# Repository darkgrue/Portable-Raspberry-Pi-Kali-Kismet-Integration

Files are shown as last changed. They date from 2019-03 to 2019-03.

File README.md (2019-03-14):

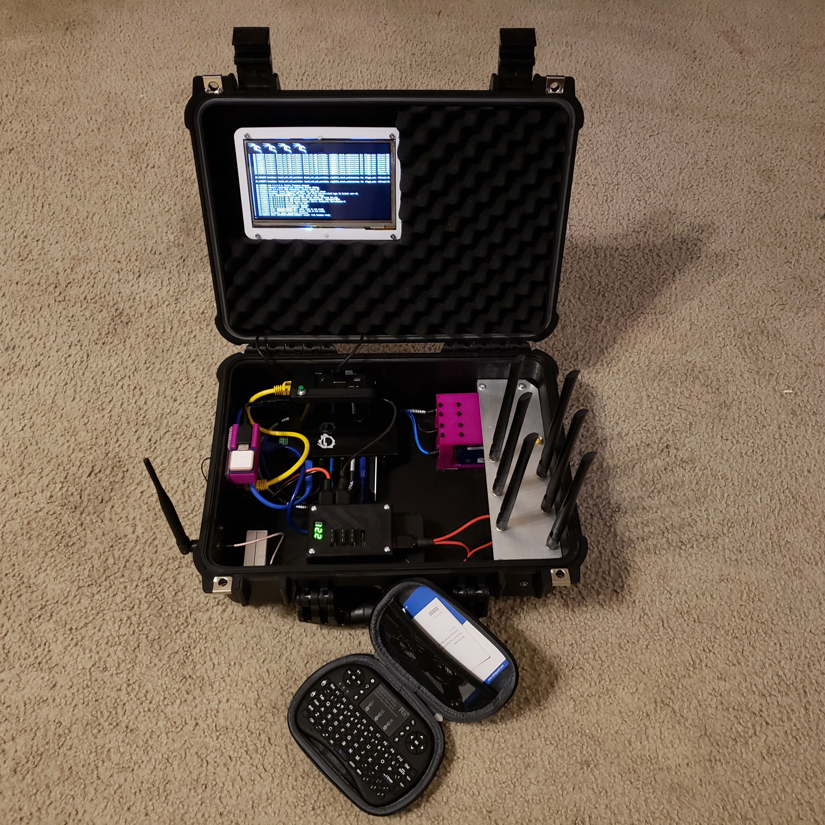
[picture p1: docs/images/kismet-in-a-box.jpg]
Kismet-in-A-Box


# Introduction

This is the basic documentation and model support files for a software and hardware integration project to build a transit-case-portable version of [Kismet](https://www.kismetwireless.net/) running on [Offsensive Security Kali Linux](https://www.offensive-security.com/kali-linux-arm-images/) (Kali Linux RaspberryPi 2 and 3) and a Raspberry Pi 3 Model B+.

The goal is to have a fully-functional Kismet platform that integrates all supported data sources in a completely portable form factor. In this case, the data sources being used are:
* Linux Wi-Fi (3x Alfa AWUS036ACH, RTL8812AU 802.11ac/a/b/g/n chipset)
* Linux Bluetooth (Cypress CYW43455 Bluetooth 4.2 chipset, onboard Raspberry Pi 3 Model B+)
* SDR RTL433 ([rtl_433](https://github.com/merbanan/rtl_433), 433.92 MHz generic data receiver)
* [Mousejack](https://github.com/BastilleResearch/mousejack) / nRF (Nordic Semiconductor nRF24LU1+ Logitech Unifying dongle, model C-U0007)
* GPS (u-blox 7, geolocation coordinates for devices)

There is room for expansion, and the as-built includes external connections for power, ethernet, and USB. A [DSTIKE Deauth Detector V2(Pre-flashed)](https://www.tindie.com/products/lspoplove/dstike-deauth-detector-v2pre-flashed/) has been included on the hub to independently monitor [deauthentication attacks](https://en.wikipedia.org/wiki/Wi-Fi_deauthentication_attack) on the 2.4GHz band.

# Bill of Materials
NOTE: Some items were bought in quantity (i.e. 3-pack, etc.) because of ease of procurement. In some cases there will be leftover/spare parts. Required quantities from packages are given for the as-built.

## Hardware
Qty. | Item | Approx. Price
------------ |------------ | -------------
1 |	[1/8" X 3" 6061 T6511 Aluminum extruded flat bar 12" long](https://www.ebay.com/itm/2-Pieces-1-8-X-3-ALUMINUM-6061-FLAT-BAR-12-long-T6511-New-Mill-Stock-125-x-3/350926360885) | $5.89
1 |	[Stanley National S838-946 2-1/2" Zinc Corner Brace- DPB113](https://www.amazon.com/dp/B00KQVM8E4) | $6.82
1 |	[Apache 3800 Weatherproof Protective Case - 16-5/16 In.](https://www.harborfreight.com/3800-weatherproof-protective-case-16-516-in-63927.html) | $39.99
as-needed | Misc screws, nuts and washers | varies
as-needed | 3M Dual Lock™ Reclosable Fastener SJ3560, Clear, 1 in | varies

## Computing Platform
Qty. | Item | Approx. Price
------------ |------------ | -------------
1 |	[CanaKit Raspberry Pi 3 B+ (B Plus) with 2.5A Power Supply (UL Listed)](https://www.amazon.com/dp/B07BC6WH7V) | $48.99
1 | [Samsung 128GB 100MB/s (U3) MicroSD EVO Select Memory Card with Adapter (MB-ME128GA/AM)](https://www.amazon.com/dp/B06XWZWYVP) | $28.99
1 |	[ModMyPi Modular (variable height) case for Raspberry Pi 2/3 - complete set with covers, spacers, screws & feet](https://www.amazon.com/dp/B01LYARY5D) | $19.95
1 | [SIIG 7-Port Industrial USB 3.0 Hub with 15KV ESD Protection](https://www.ebay.com/itm/SIIG-4-Port-and-7-Port-Industrial-USB-3-0-Hub-with-15KV-ESD-Protection/132678192728) | $34.99
1 | [Spell Foundry Sleepy Pi 2](https://spellfoundry.com/product/sleepy-pi-2/) | $56.33
1 |	[7inch HDMI 1024×600 Capacitive Touch Screen with Bicolor Case for Raspberry Pi](https://www.ebay.com/itm/7-HDMI-LCD-with-Case-800-480-Capacitive-Touch-Screen-for-Raspberry-Pi-BB-Black/262125842620) |  $67.15
1 | [Rii i8+ 2.4GHz Mini Wireless Keyboard with Touchpad Mouse,LED Backlit,Rechargable Li-ion Battery (Updated 2017,Backlit)](https://www.amazon.com/dp/B00WQG6A8C) | $21.95
1 | [Hard EVA Case for (Updated 2017,Backlit) Rii i8+ 2.4GHz Mini Wireless Keyboard by Hermitshell](https://www.amazon.com/dp/B01E8ILR60) | $9.99

## Power
Qty. | Item | Approx. Price
------------ |------------ | -------------
1 | [DC 12V 45A Anderson Powerpole Connector Power Distribution 1 input - 4 output](https://www.ebay.com/itm/DC-12V-45A-Anderson-Powerpole-Connector-Power-Distribution-1-input-4-output/183445188417) | $30.00
3 | 2A ATO blade fuse [2 required, 1 spare] | varies
1 | [TalentCell Rechargeable 72W 132WH 12V/11000mAh 9V/14500mAh 5V/26400mAh DC Output Lithium Ion Battery Pack For LED Strip and CCTV Camera, Portable Li-ion Power Bank, Black](https://www.amazon.com/dp/B016BJCRUO) | $64.99
1 | [[Real 18AWG 43x2pcs Wires] 10 Pairs DC Power Pigtail Cable, 12V 5A Male & Female Connectors for CCTV Security Camera and Lighting Power Adapter by MILAPEAK (2.1mm x 5.5 mm, Ultra Thick 18AWG)](https://www.amazon.com/dp/B072BXB2Y8) [1 M/F pair required]| $9.69
1 | [30 Amp Unassembled Red/Black Anderson Powerpole Connectors Complete with Roll Pin (10 sets)](https://www.amazon.com/dp/B01HDZ91G8) [5 sets required] | $16.47
1 | [Brccee AC 10PCS FR PVC Cover Flame Retardant Sleeve for ANDERSON Powerpole Connector Housing](https://www.amazon.com/dp/B07DCSGS9R) [4 required] | $6.99
as-needed | red-black hookup wire | varies

## Radios
Qty. | Item | Approx. Price
------------ |------------ | -------------
1 | [Stratux GPYes u-blox 7 GPS unit](https://www.amazon.com/dp/B0716BK5NT) | $15.99
3 | [Alfa Long-Range Dual-Band AC1200 Wireless USB 3.0 Wi-Fi Adapter w/2x 5dBi External Antennas – 2.4GHz 300Mbps/5GHz 867Mbps – 802.11ac & A, B, G, N](https://www.amazon.com/dp/B00VEEBOPG) | $149.97
1 | [NooElec NESDR Mini USB RTL-SDR & ADS-B Receiver Set, RTL2832U & R820T Tuner, MCX Input. Low-Cost Software Defined Radio Compatible with Many SDR Software Packages. R820T Tuner & ESD-Safe Antenna Input](https://www.amazon.com/dp/B009U7WZCA) | $19.95
1 | [Logitech C-U0007 Unifying receiver for mouse and keyboard works with any product that display the Unifying Logo (orange star, connects up to 6 devices) (C-U0007)](https://www.amazon.com/dp/B0058OU8VY) | $9.79
1 | [Stratux GPYes u-blox 7 GPS unit](https://www.amazon.com/dp/B0716BK5NT) | $15.99
1 | [DSTIKE Deauth Detector V2(Pre-flashed)](https://www.tindie.com/products/lspoplove/dstike-deauth-detector-v2pre-flashed/) | $11.00

## Antennas & RF
Qty. | Item | Approx. Price
------------ |------------ | -------------
1 | [433MHz GSM GPRS RP-SMA male Tilt-Swivel 20cm radio Antenna](https://www.ebay.com/itm/433MHz-GSM-GPRS-RP-SMA-male-Tilt-Swivel-20cm-radio-Antenna/321117288367) | $4.80
4 | [6inch RP-SMA MALE RIGHT ANGLE to RP-SMA Female RF Extension Cable RG316](https://www.ebay.com/itm/RP-SMA-MALE-RIGHT-ANGLE-to-RP-SMA-Female-RF-Extension-Cable-RG316-2in-10feet/131159786419) | $15.38
2 | [8inch RP-SMA MALE RIGHT ANGLE to RP-SMA Female RF Extension Cable RG316](https://www.ebay.com/itm/RP-SMA-MALE-RIGHT-ANGLE-to-RP-SMA-Female-RF-Extension-Cable-RG316-2in-10feet/131159786419) | $17.80
1 | [Dust Cap For SMA Jack Female or RP-SMA RF Connector With Ring Chain Silver UE](https://www.ebay.com/itm/Dust-Cap-For-SMA-Jack-Female-or-RP-SMA-RF-Connector-With-Ring-Chain-Silver-UE/332591617374) | $5.15

## Cabling
Qty. | Item | Approx. Price
------------ |------------ | -------------
1 | [Monoprice 113576 Ultra Slim Series High Speed HDMI Cable, 1ft Black](https://www.amazon.com/dp/B014RONV5K) | $9.80
1 | [VCE 2 Combos HDMI 90 and 270 Degree Male to Female Vertical Flat Adapter](https://www.amazon.com/dp/B06Y6743TL) [1 required] | $7.99
1 | [Coiled Micro USB Cable – Rerii Coiled USB to Micro USB, Right Angled, Spring, Coiled Micro USB Cable, for Micro B Device, Charging and Data SYNC, Samsung, HTC, Huawei, Sony and More](https://www.amazon.com/dp/B01HPSRYYO) | $6.99
1 | [Besgoods 3-Pack Short 1.5ft Braided Super Speed USB 3.0 Cable - Type A Male to Micro B Cable Cord for Hard Drive, Samsung Galaxy S5, Note 3 and More, Black White Blue](https://www.amazon.com/dp/B078RZG6XS) [3 required] | $11.99
1 | [SaiTech IT 4 Pack (15cm - 6inch) Adjustable Flexible USB 2.0 Male to Female Extension Plug/Socket Adapter Cable - Worlds Shortest USB 2.0 Extension Cable](https://www.amazon.com/dp/B01GA1GKYW) [2 required] | $8.59
1 | [1 ft / 30cm SuperSpeed USB 3.0 Cable A to B - USB 3 A (m) to USB 3 B (m)](https://www.amazon.com/dp/B004395680) | $6.61

## Optional
The items below are optional, to plumb the power, USB, and Ethernet connections to the outside of the case. While they are present in the as-built, they're not essential to operation.
NOTE: The external power connection is constructed of a custom Y-cable and mating connector for the Li-ion charger that uses additional PowerPole connectors, sleeves, and 2.1mm x 5.5 mm pigtail connectors, and assumes purchase of components in quantity.

Qty. | Item | Approx. Price
------------ |------------ | -------------
1 | [CNLINKO RJ45 Dual Port Ethernet Connector, Panel Mount Receptacles Socket Jack, Outdoor Waterproof IP67, Fast Data, Industrial](https://www.amazon.com/dp/B073RZHPKS) | $11.39
1 | [CNLINKO USB 3.0 Connector, Type A Female to Female, Panel Mount Receptacles Socket Jack, Dual USB Port, Outdoor Waterproof IP67, Data + Power, Panel Pass, Industrial Standard](https://www.amazon.com/dp/B01N6ERRX7) | $12.62
1 | [Threaded Panel Mount, Anderson PowerPole PP15-PP45](https://www.ebay.com/itm/Threaded-Panel-Mount-Anderson-PowerPole-PP15-PP45/173536212677) | $7.38
1 | [LOHASIC USB 3.0 Ultra High Speed Cable , 1 Feet , Male A Plug to A Plug -Blue,1FT](https://www.amazon.com/dp/B00KMQ7O5G) | $6.99
1 | [Monoprice Flexboot Cat6 Ethernet Patch Cable - Network Internet Cord - RJ45, Stranded, 550Mhz, UTP, Pure Bare Copper Wire, 24AWG, 1ft, Yellow](https://www.amazon.com/dp/B00AJHCMG4) | $2.22

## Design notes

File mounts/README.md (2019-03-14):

## AWUS036ACH multi-mount (three) - bottom.stl
AWUS036ACH multi-mount (three) - bottom.stl
STL file for the bottom half of the three-gang AWUS036ACH mount.

## AWUS036ACH multi-mount (three) - top.stl
AWUS036ACH multi-mount (three) - top.stl
STL file for the top half of the three-gang AWUS036ACH mount.

## AWUS036ACH multi-mount (two) - bottom.stl
AWUS036ACH multi-mount (two) - bottom.stl
STL file for the bottom half of the two-gang AWUS036ACH mount (not used in as-built).

## AWUS036ACH multi-mount (two) - top.stl
AWUS036ACH multi-mount (two) - top
STL file for the top half of the two-gang AWUS036ACH mount (not used in as-built).

## AWUS036ACH multi-mount.scad
AWUS036ACH multi-mount.scad
OpenSCAD source for the parametric AWUS036ACH mount.

## Stratux GPYes u-blox 7 GPS mount.scad
Stratux GPYes u-blox 7 GPS mount.scad
OpenSCAD source for the GPS mount.

## Stratux GPYes u-blox 7 GPS mount.stl
Stratux GPYes u-blox 7 GPS mount.stl
STL file for the GPS mount.

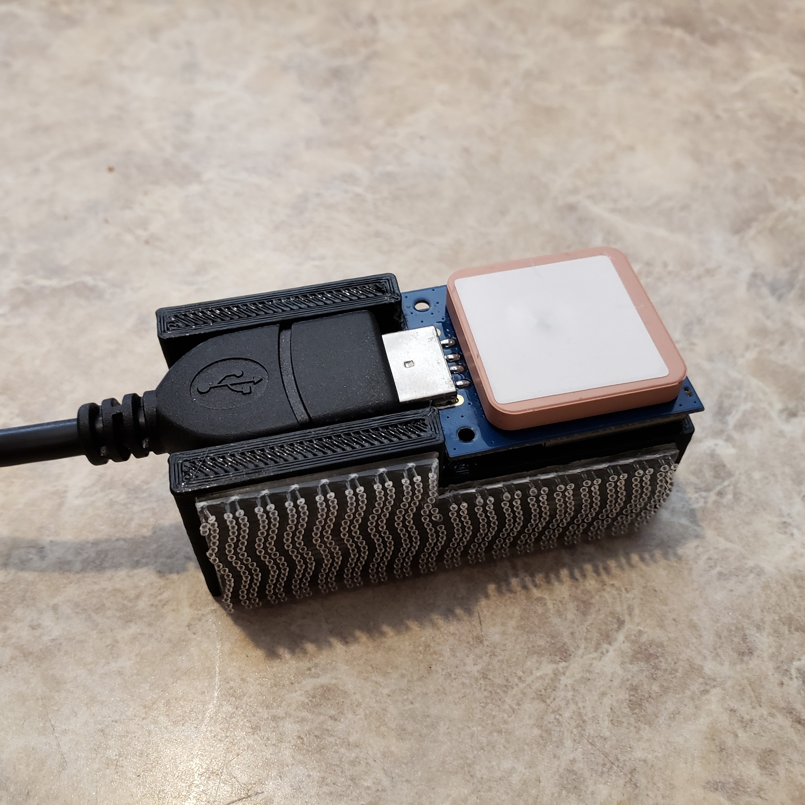
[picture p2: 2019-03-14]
docs/images/Stratux GPYes u-blox 7 GPS Mount.jpg

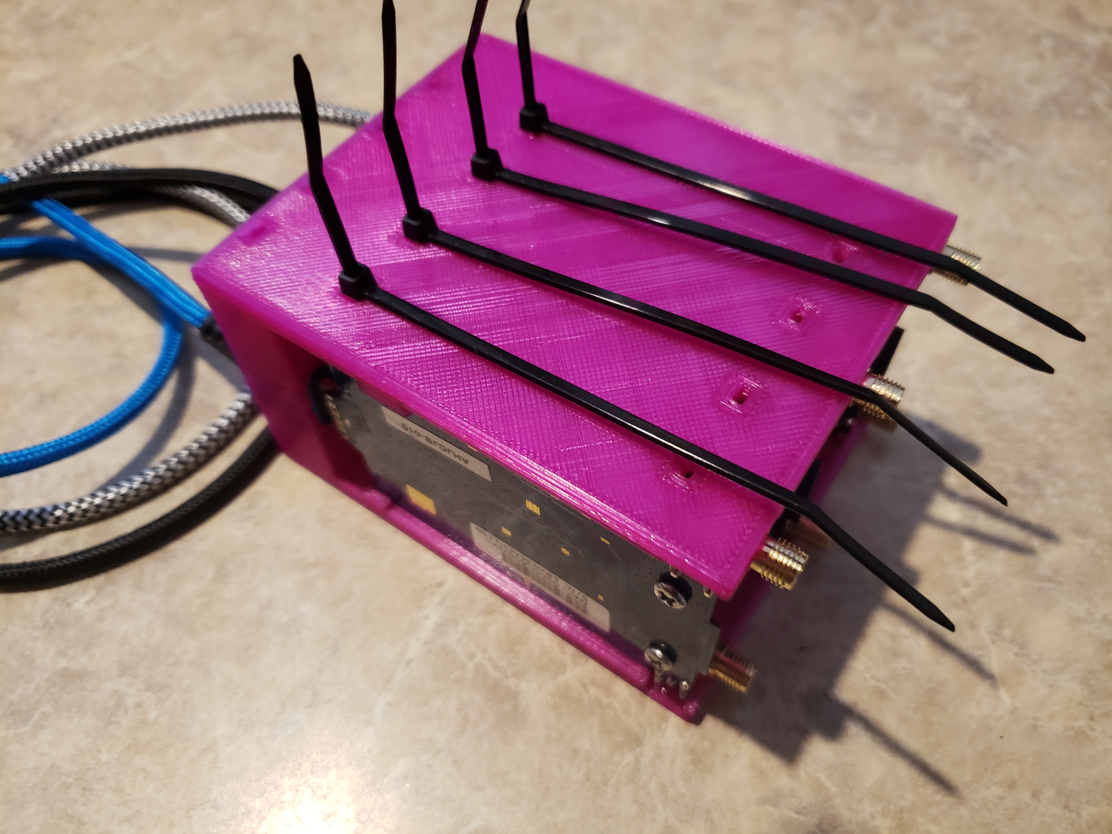
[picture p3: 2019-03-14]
docs/images/Alfa AWUS036ACH Bare Board Multi-Mount - partial.jpg

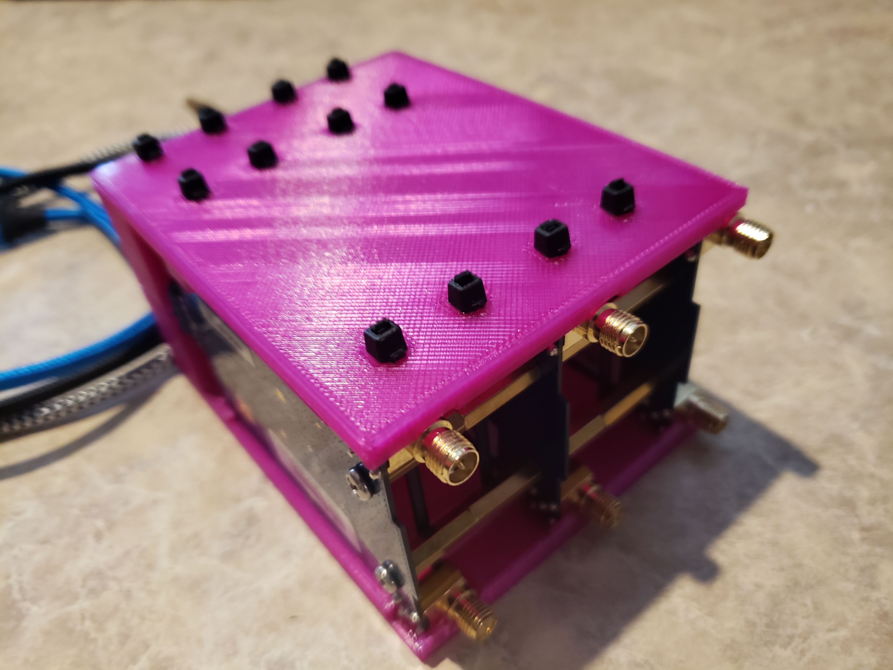
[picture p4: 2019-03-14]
docs/images/Alfa AWUS036ACH Bare Board Multi-Mount - finished.jpg

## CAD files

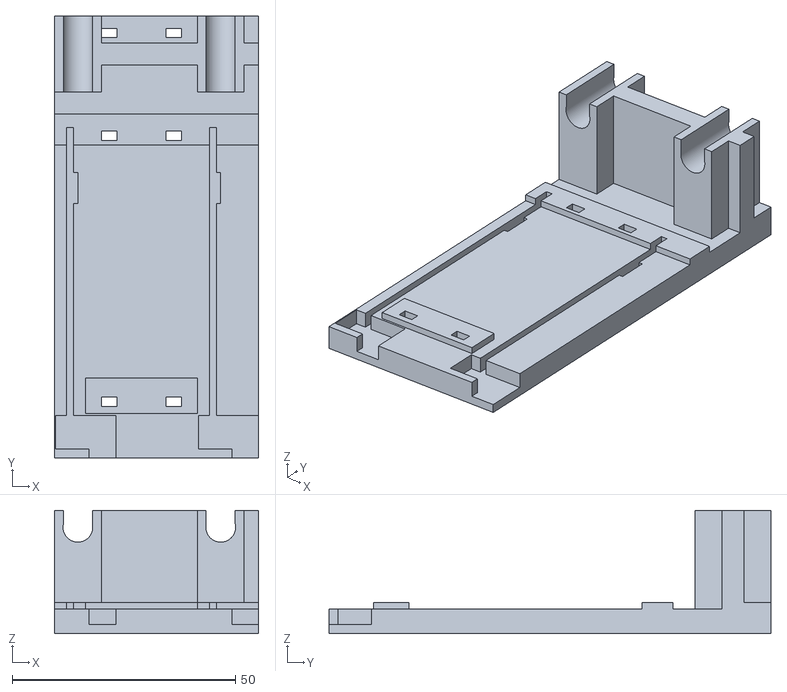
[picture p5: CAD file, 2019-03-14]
mounts/AWUS036ACH multi-mount (two) - bottom.stl
45.7 x 99.0 x 27.6

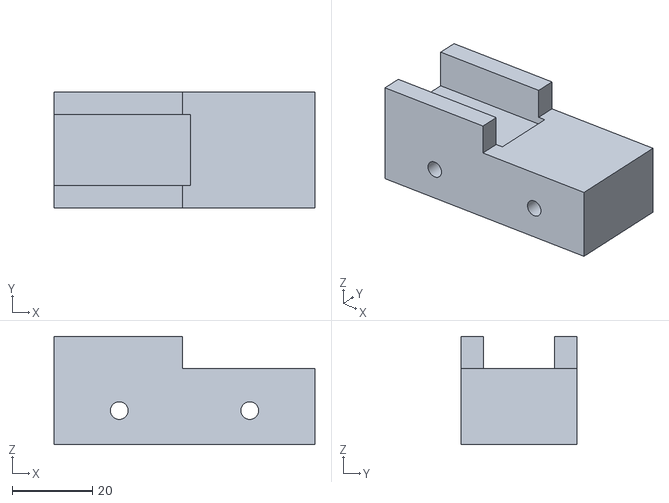
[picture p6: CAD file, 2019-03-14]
mounts/Stratux GPYes u-blox 7 GPS mount.stl
65.0 x 28.9 x 27.0

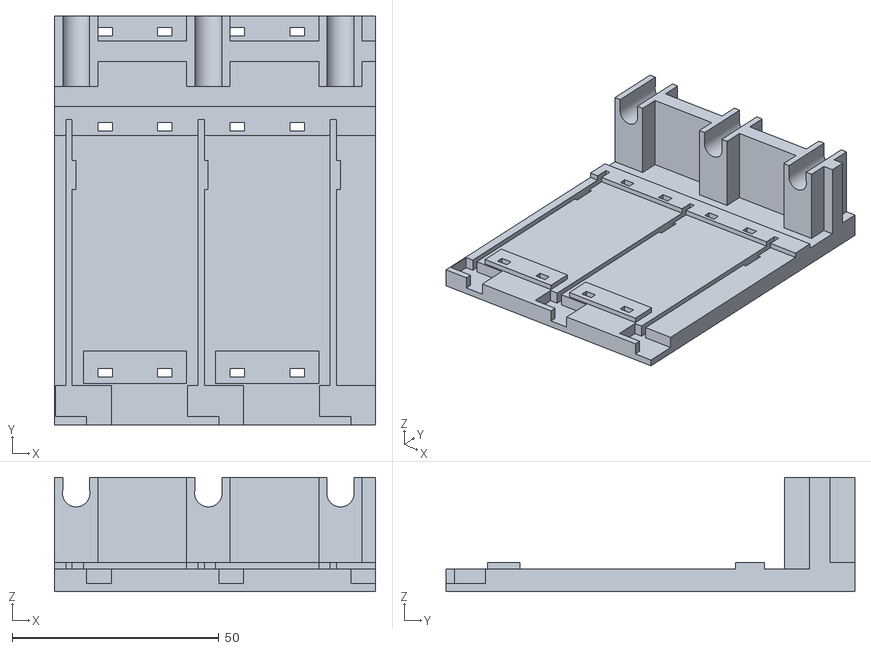
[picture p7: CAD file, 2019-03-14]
mounts/AWUS036ACH multi-mount (three) - bottom.stl
77.7 x 99.0 x 27.6

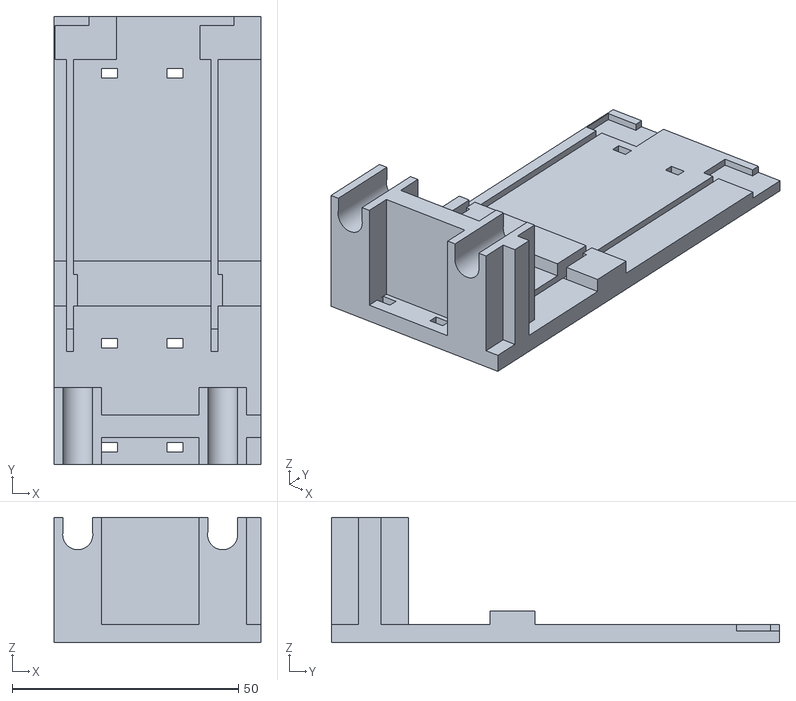
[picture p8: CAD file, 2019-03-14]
mounts/AWUS036ACH multi-mount (two) - top.stl
45.7 x 99.0 x 27.6

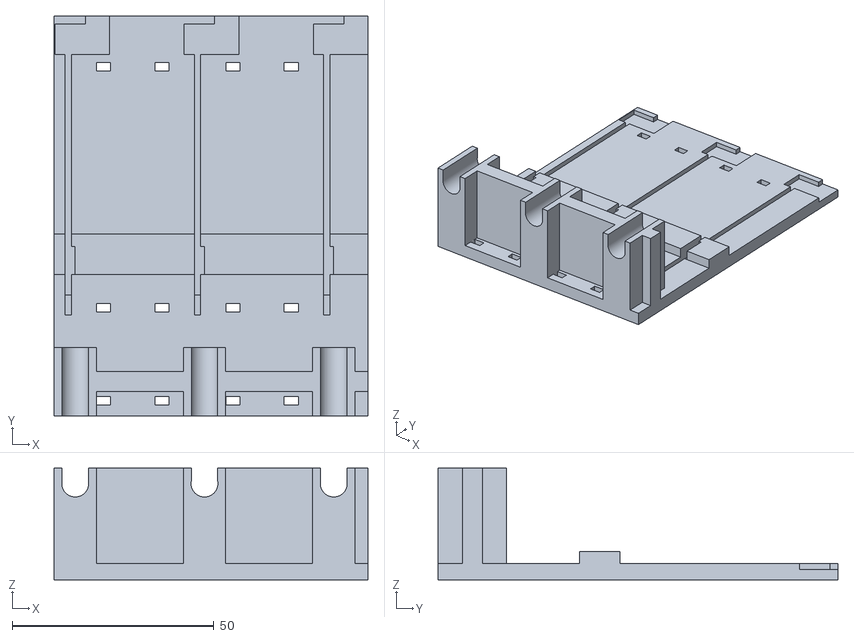
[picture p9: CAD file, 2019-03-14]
mounts/AWUS036ACH multi-mount (three) - top.stl
77.7 x 99.0 x 27.6

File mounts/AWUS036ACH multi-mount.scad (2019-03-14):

// raise for higher detail
$fn = 64;

// Number of radio modules, must be a number greater than one!
$NUMBEROFMODULES = 3;

$FLATTEN = false;

module board_cutout() {
    cube([1.05 + 0.5, 70 + 0.05, 3.5 + 1]);
    translate([-2.5, -2, 0])
        cube([11 + 2.5, 7 + 0.5, 3.5 + 1]);
    translate([0, 53, 0])
        cube([2.5, 7, 3.5 + 1]);
    translate([0, 65, 0])
        cube([1.05 + 0.5, 5, 5 + 1]);
    translate([(1.05 + 0.5) + 6.5, -(2) + (7 + 0.5 + 2 + 1) / 2 - 2 - 1, (3.5 + 1) / 2])
        cube([3.5 + 2.5, (7 + 0.5) + 2 + 1, 3.5 + 1], center = true);
}

module usb_support() {
    translate([((1.05 + 0.5) / 2) + 1.75, 0, 0]) {
        difference() {
            union() {
                translate([0, (-4 + 99) - 17 / 2, -2 + ((20.5) + 14.75 / 2 - 0.25) / 2]) {
                    translate([0, 0, 0])
                        cube([6.5 + (2 * 2), 17, (20.5) + 14.75 / 2 - 0.25], center = true);
                    translate([32, 0, 0])
                        cube([6.5 + (2 * 2), 17, (20.5) + 14.75 / 2 - 0.25], center = true);
                    // cable support buttress
                    translate([-((6.5 + (2 * 2)) / 2) + 45.725 / 2, 0, 0])
                        cube([45.725, 5, (20.5) + 14.75 / 2 - 0.25], center = true);
                }
            }

            union() {
                translate([0, -(4 - 99) - 19 / 2 + 1, (-2 + 20.5)]) {
                    translate([0, 0, (14.75 / 2)]) {
                        translate([0, 0, 0])
                            cube([6.5, 19, 14.75 - 6.65], center = true);
                        translate([32, 0, 0])
                            cube([6.5, 19, 14.75 - 6.65], center = true);
                    }

                    rotate([90, 0, 0]) {
                            translate([0, 6.65 / 2, 0]) {
                                translate([0, 0, 0])
                                   cylinder(d = 6.65, h = 19, center = true);
                                translate([0, 14.75 - 6.65, 0])
                                   cylinder(d = 6.65, h = 19, center = true);
                            }

                            translate([32, 6.65 / 2, 0]) {
                                translate([0, 0, 0])
                                   cylinder(d = 6.65, h = 19, center = true);
                                translate([0, 14.75 - 6.65, 0])
                                   cylinder(d = 6.65, h = 19, center = true);
                            }
                    }
                }                            
            }
        }
    }
}

module zip_cutout() {
    translate([(4.7 + 0.5) / 2, 0, -0.5]) {
        cube([4.7 + 0.5, 4 + 0.9, 4 + 1.9], center = true);
        translate([0, ((1.2 + 0.9) - (4 + 0.9)) / 2, -(4 + 1.9) / 2 + (67 + 1) / 2])
            cube([2.6 + 0.9, 1.2 + 0.9, 67 + 1], center = true);
    }
}

module bottom() {
    translate([0, 0, 2]) {
        difference() {
            union() {
                translate([-2.725, 0, -2]) {
                    // base
                    translate([0, -4, 0])
                        cube([45.725, 99, 3.5 + 2]);
                    // zip tie bolsters
                    translate([2.725 + (5 + (1.05 + 0.9) + ((32 - (4.7 + 0.9) - 5) - (5 + (1.05 + 0.9))) / 2 + (4.7 + 0.5) / 2) - 25 / 2, 6, 0])
                        cube([25, 7.9, 5 + 2]);
                    translate([0, 70 - 0.4 - (5 + 2) / 2, 0])
                        cube([45.725, 5 + 2, 5 + 2]);
                    translate([0, (99) - 11, 0])
                        cube([45.725, 5 + 2, 5 + 2]);
                 }

                // USB 3.0 cable supports
                translate([0, 0, 0])
                    mirror([0, 0, 0])
                        usb_support();
            }

            translate([0, 0, 0]) {
                translate([0, 0, 0])
                    board_cutout();
                translate([32, 0, 0])
                    board_cutout();
            }

            translate([0, 0, 0.9]) {
                translate([5 + (1.05 + 0.9), 0, 0]) {
                    translate([0, 10, 0])
                        zip_cutout();
                    translate([0, 70 - 0.4, 0])
                        zip_cutout();
                    translate([0, (99 - 6) - 0.4, 0])
                        zip_cutout();
                }

                translate([32 - (4.7 + 0.9) - 5, 0, 0]) {
                    translate([0, 10, 0])
                        zip_cutout();
                    translate([0, 70 - 0.4, 0])
                        zip_cutout();
                    translate([0, (99 - 6) - 0.4, 0])
                        #zip_cutout();
                }
            }
        }
    }
}

module top() {
    translate([0, 0, 50.25]) {
        difference() {
            union() {
                translate([-2.725, 0, 1.5]) {
                    // base
                    translate([0, -4, 0])
                        cube([45.725, 99, 2 + 2]);
                    // board guide
                    translate([0, 50, (-1.5) - 1.5])
                        cube([45.725, 10, 2+ 5]);
                }

                // USB 3.0 cable supports
                translate([0, 0, 1.5 + 2])
                    mirror([0, 0, 1])
                        usb_support();
            }

            translate([0, 0, -1.5]) {
                translate([0, 0, 0])
                    board_cutout();
                translate([32, 0, 0])
                    board_cutout();
            }

            translate([0, 0, -50.25]) {
                translate([5 + (1.05 + 0.9), 0, 0]) {
                    translate([0, 10, 0])
                        zip_cutout();
                    translate([0, 70 - 0.4, 0])
                        zip_cutout();
                    translate([0, (99 - 6) - 0.4, 0])
                        zip_cutout();
                }

                translate([32 - (4.7 + 0.9) - 5, 0, 3]) {
                    translate([0, (99 - 6) - 0.4, 0])
                        zip_cutout();
                    translate([0, 70 - 0.4, 0])
                        zip_cutout();
                    translate([0, 10, 0])
                        #zip_cutout();
                }
            }
        }
    }
}

difference() {
    union() {
        $offset = 0;
        for(i = [0 : ($NUMBEROFMODULES - 2)]) {
            translate([32 * i, 0, 0])
                bottom();

            if ($FLATTEN) {
                translate([32 * i, -(2.725 * 2) - 5, (3 + 50.25) + 5.5])
                    rotate([0, 180, 180])
                        top();
            } else {
                translate([32 * i, 0, 0])
                    rotate([0, 0, 0])
                        top();
            }
        }
    }
    
    union() {
        for(i = [0 : ($NUMBEROFMODULES - 2)]) {
            translate([32 * i, 0, 2 + 0.9]) {
                translate([5 + (1.05 + 0.9), 0, 0]) {
                    translate([0, 10, 0])
                        #zip_cutout();
                    translate([0, 70 - 0.4, 0])
                        #zip_cutout();
                    translate([0, (99 - 6) - 0.4, 0])
                        #zip_cutout();
                }
            }

            if ($FLATTEN) {
                translate([0, -(2.725 * 2) - 5, (50.25) + 10.1])
                    rotate([0, 180, 180])
                        translate([32 * i, 0, 2 + 0.9]) {
                            translate([5 + (1.05 + 0.9), 0, 0]) {
                                translate([0, 10, 0])
                                    #zip_cutout();
                                translate([0, 70 - 0.4, 0])
                                    #zip_cutout();
                                translate([0, (99 - 6) - 0.4, 0])
                                    #zip_cutout();
                            }
                        }
            }
        }
    }
}

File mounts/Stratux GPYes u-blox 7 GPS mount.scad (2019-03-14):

// raise for higher detail
$fn = 64;

module fillet(r, h) {
    translate([r / 2, r / 2, 0])

        difference() {
            cube([r + 0.01, r + 0.01, h], center = true);

            translate([r / 2, r / 2, 0])
                cylinder(r = r, h = h + 1, center = true);

        }
}

difference() {
    union() {
        translate([65 / 2, 28.85 / 2, 27 / 2])
            cube([65, 28.85, 27], center = true);
    }

    union() {
        translate([35 / 2 - 1, 28.85 / 2, (11 / 2) + 27 - 10])
            cube([35, 17.75, 11], center = true);
        translate([65 - 34 / 2 + 1, 28.85 / 2, ((11 - 2) / 2) + (27 - 10) + 2])
            cube([34, 30.85, 11 - 2], center = true);
 
        // #8 screw holes
        translate([16.25, 30.85 / 2 - 1, 8.5]) {
            rotate([90, 0, 0]) {
                translate([0, 0, 0]) {
                    #cylinder(d = ((0.9927 * 4.064) + 0.3602), h = 30.85, center = true);
                }
                translate([16.25 * 2, 0, 0]) {
                    #cylinder(d = ((0.9927 * 4.064) + 0.3602), h = 30.85, center = true);
                }
            }
        }
    }
}

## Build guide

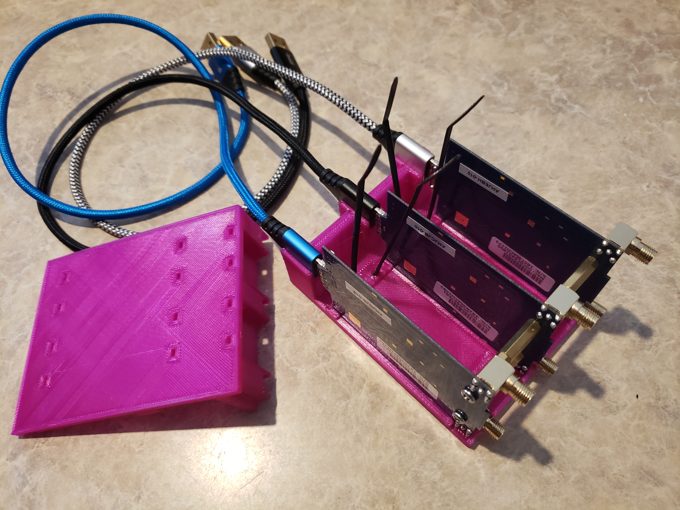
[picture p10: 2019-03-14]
docs/images/Alfa AWUS036ACH Bare Board Multi-Mount - unassembled.jpg

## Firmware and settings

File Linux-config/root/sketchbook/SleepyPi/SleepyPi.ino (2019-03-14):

// 
// This sketch merges functionality from:
// https://github.com/SpellFoundry/SleepyPi2/blob/master/examples/ButtonOnOff2/ButtonOnOff2.ino and
// https://github.com/SpellFoundry/SleepyPi2/blob/master/examples/LowVoltageShutdown/LowVoltageShutdown.ino and
// https://github.com/SpellFoundry/SleepyPi2/blob/master/examples/ButtonOnOff3/ButtonOnOff3.ino
// by Spell Foundry (https://spellfoundry.com/) to create an example that
// implements a low voltage disconnect function like a UPS. When the supply
// voltage falls below the low threshold for 30 seconds, the Arduino signals
// the RPi to shutdown. When the voltage recovers to above the power-on
// threshold, the RPi boots.
//
// If the RPi shuts down or reboots, it idles after shutdown at a value around
// 109mA. We can then detect this current and decide that the RPi is in a
// reboot, or that it has reached the shutdown state and the Sleepy Pi can
// safely remove power and go to sleep itself.
//
// The low voltage shutdown can be overridden by pressing the button. The RPi
// will wake on button press and stay powered for one hour. Extend the time to
// one hour again by pressing the button. The override is ignored when voltage
// is below the force-off voltage.
//
// To shutdown the RPi, hold the User Button for 2-8 seconds. If the button is
// held down more than 8 seconds the Sleepy Pi will cut the power to the RPi
// regardless of any handshaking.
// 
// While powered, the state, supply voltage, and current prints to the serial
// monitor twice per second.
//


// **** INCLUDES *****
#include "SleepyPi2.h"
#include <Time.h>
#include <LowPower.h>
#include <PCF8523.h>
#include <Wire.h>


// Constants
#define kBUTTON_POWEROFF_TIME_MS  2000                // 2 seconds
#define kBUTTON_FORCEOFF_TIME_MS  8000                // 8 seconds

#define kPI_CURRENT_THRESHOLD_MA  120

#define POWER_ON_VOLTAGE          99.9
#define POWER_OFF_VOLTAGE         11.4
#define FORCE_OFF_VOLTAGE         9.3

#define LOW_VOLTAGE_TIME_MS       30000               // 30 seconds
#define OVERRIDE_TIME_MS          3600000             // 1 hour

const int LED_PIN = 13;


// States
typedef enum {
  eWAIT = 0,
  eBUTTON_PRESSED,
  eBUTTON_WAIT_ON_RELEASE,
  eBUTTON_HELD,
  eBUTTON_RELEASED
}ebutton_state;
String ebutton_map[] = { "eWAIT", "eBUTTON_PRESSED", "eBUTTON_WAIT_ON_RELEASE", "eBUTTON_HELD", "eBUTTON_RELEASED" };

typedef enum {
  ePI_OFF = 0,
  ePI_BOOTING,
  ePI_ON,
  ePI_SHUTTING_DOWN
}epi_state;
String epi_map[] = { "ePI_OFF", "ePI_BOOTING", "ePI_ON", "ePI_SHUTTING_DOWN" };

volatile bool  buttonPressed = false;
ebutton_state  button_state = eWAIT;
epi_state      pi_state = ePI_OFF;
bool           pi_reboot = false;
unsigned long  time = 0,
               timePress = 0,
               timeLow = 0,
               timeVeryLow = 0;
float          min_pi_current = 9999;

// Setup the Periodic Timer.
// Use one of eTB_SECOND or eTB_MINUTE or eTB_HOUR.
eTIMER_TIMEBASE PeriodicTimer_Timebase = eTB_SECOND;  // timebase set to seconds
uint8_t         PeriodicTimer_Value= 5;               // timer interval in units of timebase (e.g. 5 seconds)


void button_isr() {
  // A handler for the Button interrupt.
  buttonPressed = true;
}

void alarm_isr() {
  // A handler for the Alarm interrupt.
}

void setup() {
  SleepyPi.simulationMode = false;                    // disable simulation mode

  // Configure "standard" LED pin.
  pinMode(LED_PIN, OUTPUT);
  digitalWrite(LED_PIN, LOW);                         // turn off LED

  SleepyPi.enablePiPower(false);
  SleepyPi.enableExtPower(false);

  // Allow wake-up triggered by button press.
  attachInterrupt(1, button_isr, LOW);                // button pin

  SleepyPi.rtcInit(true);

  // Initialize serial communication.
  Serial.begin(9600);
  Serial.println("Setup() complete...");
  delay(50);
}

void loop() {
  bool pi_handshake;
  bool pi_running;
  unsigned long buttonTime;
  float supply_voltage;
  float pi_current;

  // Enter power-down state with ADC and BOD module disabled.
  // Wake up when wake button is pressed.
  // Once button is pressed, stay awake - this allows the timer to keep running.

  time = millis();
  // Check for time rollover.
  if((time < timeLow) || (time < timeVeryLow) || (time < timePress)) {
    timeLow = time;
    timeVeryLow = time;
    timePress = 0;
  }

  switch(button_state) {
    case eWAIT:
      SleepyPi.rtcClearInterrupts();  

      // Allow wake up alarm to trigger interrupt on falling edge.
      attachInterrupt(0, alarm_isr, FALLING);         // alarm pin

      // Set the Periodic Timer
      SleepyPi.setTimer1(PeriodicTimer_Timebase, PeriodicTimer_Value);

      // Enter power down state with ADC and BOD module disabled.
      // Wake up when wake up pin is low or Alarm fired.
      SleepyPi.powerDown(SLEEP_FOREVER, ADC_OFF, BOD_OFF); 
      // GO TO SLEEP....
      // ....
      // ....
      // I'm awake !!!  
      digitalWrite(LED_PIN, HIGH);                     // turn on LED
      // What woke me up? Was it a button press or a scheduled wake?
      // Check on button press.
      if(buttonPressed == false) {        
        // Woken by an alarm interrupt.
        // Do some general housekeeping.
        // ...Check on our RPi.
        pi_handshake = SleepyPi.checkPiStatus(false);
        pi_running = SleepyPi.checkPiStatus(kPI_CURRENT_THRESHOLD_MA, false);
        switch(pi_state) {           
          case ePI_BOOTING:
            // Check if we have finished booting.
            if(pi_handshake == false) {
              if(pi_running == false) {
                // Shock, horror! it's not running!!
                // Assume it has been manually shutdown, so let's cut the power.
                Serial.println("Pi not running, forcing power off...");
                SleepyPi.enablePiPower(false);
                SleepyPi.enableExtPower(false);
                pi_state = ePI_OFF;
              }
              else {
                // Still not completed booting so let's carry on waiting...
                pi_state = ePI_BOOTING;
              }
            }
            else {
              // We have booted up!
              pi_state = ePI_ON;
              pi_reboot = false;
              Serial.println("Pi boot process complete.");
            }
            break;
          case ePI_ON:
            // Check if it is still on?
            if(pi_handshake == false) {
              if(pi_running == false) {
                // Shock, horror! it's not running!!
                // Assume it has been manually shutdown, so let's cut the power.
                Serial.println("Pi not running, forcing power off...");
                SleepyPi.enablePiPower(false);
                SleepyPi.enableExtPower(false);
                pi_state = ePI_OFF;
              }
              else {
                // Handshake is down, but it's still drawing power above the idle threshold.
                // Assume reboot or shutdown initiated manually.
                Serial.println("Handshake dropped while Pi running, transitioning to shutdown state.");
                pi_state = ePI_SHUTTING_DOWN;
              }
            }
            else {
              // Still on, all's well. Keep this state.
              pi_state = ePI_ON;
              pi_reboot = false;
            }
            break;
          case ePI_SHUTTING_DOWN:
            // Is it still shutting down?
            if(pi_handshake == false) {
              if(pi_running == false) {
                // Finished a shutdown, force the power off.
                Serial.println("Pi finished shutdown, powering off...");
                SleepyPi.enablePiPower(false);
                SleepyPi.enableExtPower(false);
                pi_state = ePI_OFF;
                pi_reboot = false;
              }
              else {
                // Handshake is down, but it's still drawing power above the idle threshold.
                Serial.println("Handshake dropped while Pi shutting down, waiting for reboot or shutdown.");
                pi_reboot = true;
              }
            }
            else {
              if(pi_reboot == true) {
                // Handshake re-asserted during shutdown without Pi going idle, assume reboot initiated manually.
                Serial.println("Pi hardware handshake re-asserted while shutting down, transitioning to booting state.");
                pi_state = ePI_BOOTING;
                pi_reboot = false;
              }
              else {
                // Still shutting down. Keep this state.
                pi_state = ePI_SHUTTING_DOWN;
              }
            }
            break;
          case ePI_OFF:
            if(pi_handshake) {
              Serial.println("Pi hardware handshake asserted, transitioning to running state.");
              SleepyPi.enablePiPower(true);
              SleepyPi.enableExtPower(true);
              pi_state = ePI_ON;
              pi_reboot = false;
            }
            else if (pi_running) {
              // Handshake is down, but it's still drawing power above the idle threshold.
              Serial.println("Handshake dropped while Pi shutting down, waiting for reboot or shutdown.");
              SleepyPi.enablePiPower(true);
              SleepyPi.enableExtPower(true);
              pi_state = ePI_SHUTTING_DOWN;
              pi_reboot = true;
            }
            break;
          default:                                    // intentional drop-thru
            // RPi off, so we'll continue to wait for a button press to tell us to switch it on.
            delay(10);
            pi_state = ePI_OFF;
            break;
        }
        button_state = eWAIT;                         // set state to loop back around and go to sleep again

        // Disable external pin interrupt on wake-up pin.
        detachInterrupt(0);
        SleepyPi.ackTimer1();
      }
      else {
        Serial.println("Button press event...");
        // This was a button press so change the button state (and stay awake).
        buttonPressed = false;
        // Disable the alarm interrupt.
        detachInterrupt(0);
        // Disable external pin interrupt on wake-up pin.
        detachInterrupt(1);
        button_state = eBUTTON_PRESSED;
      }
      break;
    case eBUTTON_PRESSED:
      buttonPressed = false;
      timePress = millis();                           // log press time
      pi_handshake = SleepyPi.checkPiStatus(false);
      if(pi_handshake == false) {
        Serial.println("Pi not running, powering on...");
        // Switch on the Pi.
        SleepyPi.enablePiPower(true);
        SleepyPi.enableExtPower(true);
        pi_state = ePI_BOOTING;
      }
      button_state = eBUTTON_WAIT_ON_RELEASE;
      digitalWrite(LED_PIN, HIGH);                    // turn on LED
      attachInterrupt(1, button_isr, HIGH);           // will go high on release
      break;
    case eBUTTON_WAIT_ON_RELEASE:
      if(buttonPressed == true) {
        detachInterrupt(1);
        buttonPressed = false;
        time = millis();                              // log release time
        button_state = eBUTTON_RELEASED;
      }
      else {
        // Carry on waiting.
        button_state = eBUTTON_WAIT_ON_RELEASE;
      }
      break;
    case eBUTTON_RELEASED:
      pi_handshake = SleepyPi.checkPiStatus(false);
      if(pi_handshake == true) {
        // Check how long we have held button for.
        buttonTime = time - timePress;
        if(buttonTime > kBUTTON_FORCEOFF_TIME_MS) {
          Serial.println("Button long-pressed, forcing power off...");
          // Force Pi off.
          SleepyPi.enablePiPower(false);
          SleepyPi.enableExtPower(false);
          pi_state = ePI_OFF;
        }
        else if (buttonTime > kBUTTON_POWEROFF_TIME_MS) {
          Serial.println("Button pressed, starting shutdown...");
          // Start a shutdown.
          pi_state = ePI_SHUTTING_DOWN;
          SleepyPi.piShutdown();
          SleepyPi.enableExtPower(false);
        }
        else {
          // Button not held long enough, do nothing.
          Serial.println("Button released, no action taken...");
        }
      }
      else {
        // Pi not running.
      }
      attachInterrupt(1, button_isr, LOW);            // button pin
      button_state = eWAIT;
      break;
    default:
      break;
  }

  // Diagnostics logging.
  Serial.print("St: " + epi_map[pi_state] +
    ", Rb: " + String(pi_reboot ? "true" : "false") +
    ", PiH: " + String(pi_handshake ? "true" : "false") +
    ", PiR: " + String(pi_running ? "true" : "false") +
    ", B: " + ebutton_map[button_state]);
  delay(10);                                          // voltage reading is artificially high if we don't delay first
  supply_voltage = SleepyPi.supplyVoltage();
  pi_current = SleepyPi.rpiCurrent();
  if(pi_current < min_pi_current) {
    min_pi_current = pi_current;
  }
  Serial.print("; Input: ");
  Serial.print(supply_voltage);
  Serial.print(" V (");
  if(supply_voltage > POWER_OFF_VOLTAGE) {
    Serial.print("normal");
  }
  else if(supply_voltage > FORCE_OFF_VOLTAGE) {
    Serial.print("below power-off");
  }
  else {
    Serial.print("below force-off");
  }
  Serial.print("), ");
  Serial.print(pi_current);
  Serial.println(" mA");
  Serial.print(" (min: ");
  Serial.print(min_pi_current);
  Serial.println(" mA)");

  if((button_state == eWAIT) || (button_state == eBUTTON_RELEASED)) {
    digitalWrite(LED_PIN, LOW);                         // turn off LED
  }

  // Boot or shutdown based on supply voltage.
  if((pi_running == true) || (pi_handshake == true)) {
    if(supply_voltage > POWER_OFF_VOLTAGE) {
      // Voltage is normal. Reset the low voltage counter.
      timeLow = time;
    }
    if(supply_voltage > FORCE_OFF_VOLTAGE) {
      timeVeryLow = time;
    }
    // Check for low voltage.
    // Allow override with the button during low voltage state, but not during very low voltage/force-off state.
    if((time - timeVeryLow > LOW_VOLTAGE_TIME_MS) ||
      ((time - timeLow > LOW_VOLTAGE_TIME_MS) && (timePress == 0 || (time - timePress > OVERRIDE_TIME_MS)))) {
      Serial.println("Voltage shutdown point reached, starting shutdown...");
      // Start a shutdown.
      pi_state = ePI_SHUTTING_DOWN;
      SleepyPi.piShutdown();
      SleepyPi.enableExtPower(false);
    }
  }
  else {
    // Check for voltage recovery.
    if(supply_voltage >= POWER_ON_VOLTAGE) {
      Serial.println("Recovery voltage reached, powering on...");
      // Switch on the Pi.
      SleepyPi.enablePiPower(true);
      SleepyPi.enableExtPower(true);
      pi_state = ePI_BOOTING;
    }
  }

  // Don't overload the serial buffer.
  delay(500);
}

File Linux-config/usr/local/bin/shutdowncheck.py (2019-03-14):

#!/usr/bin/python

import RPi.GPIO as GPIO
import signal
import os
import syslog
import time

CMD_PI_SHUTDOWN = 24
PI_IS_RUNNING = 25

SIGNALS_TO_NAMES_DICT = dict((getattr(signal, n), n) \
	for n in dir(signal) if n.startswith('SIG') and '_' not in n)

def cleanup(*args):
	syslog.syslog(syslog.LOG_INFO, 'Exiting on %s (%d). Telling Sleepy Pi system is NOT running on Pin %d.' % (SIGNALS_TO_NAMES_DICT[sig], sig, PI_IS_RUNNING))
	GPIO.output(PI_IS_RUNNING, GPIO.LOW)
	os._exit(0)

syslog.openlog('SleepyPi')
syslog.syslog(syslog.LOG_INFO, 'Telling Sleepy Pi 2 that system is running on pin %d.' % (PI_IS_RUNNING))

GPIO.setwarnings(False)
GPIO.setmode(GPIO.BCM)
GPIO.setup(CMD_PI_SHUTDOWN, GPIO.IN)
GPIO.setup(PI_IS_RUNNING, GPIO.OUT)
GPIO.output(PI_IS_RUNNING, GPIO.HIGH)

while True:
	if (GPIO.input(CMD_PI_SHUTDOWN)):
		syslog.syslog(syslog.LOG_INFO, 'Sleepy Pi 2 is requesting shutdown on %d.' % (CMD_PI_SHUTDOWN))
		os.system('shutdown -h now')
		break

	for sig in (signal.SIGABRT, signal.SIGINT, signal.SIGTERM):
		signal.signal(sig, cleanup)

	time.sleep(0.5)
